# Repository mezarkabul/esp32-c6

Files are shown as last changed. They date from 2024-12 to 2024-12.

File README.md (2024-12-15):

---

# ESP32-C6 Multi-Sensor Board

## Overview
This repository provides the hardware design, block diagrams, and schematics for the ESP32-C6 Multi-Sensor Board. The board integrates Wi-Fi/Bluetooth communication, motor driver control, and IMU sensor, making it suitable for IoT and robotics applications.

esp32-c6-block_diagram

---

## Features & Block Diagram

The ESP32-C6 Multi-Sensor Board includes the following features:

### **Power Management**
- **Power Input:** 5V @ 250mA via connector  
- **Battery Management:**
  - Battery Charger (max 200mA charging current)
  - Voltage Regulator: Converts 4.2V to 3.3V  
  - Battery Level Monitoring via ADC  

### **Microcontroller**
- **ESP32-C6:**
  - Wi-Fi 6 and BLE 5.0 support
  - GPIOs for control and communication  
  - I2C for peripherals  

### **Motor Driver**
- **DRV8830 Motor Driver:**  
  - Controlled via I2C  
  - Outputs: **Motor_P** and **Motor_N**  
  - Supports motor currents up to 400mA  

### **Sensors**
- **IMU (ICM-42605):**  
  - Accelerometer and Gyroscope  
  - Interrupt Pins: **INT1** and **INT2/FSYNC**  

### **User Interface**
- **RGB LED:** Controlled via 3 PWM GPIOs:  
  - **GPIO10:** Red Channel  
  - **GPIO11:** Green Channel  
  - **GPIO12:** Blue Channel  
- **External Button:** GPIO Input for interrupts  

---

## Pinout Table

| **Pin Name** | **ESP32-C6 GPIO**  | **Description** | **Function** |
|---|---|---|---|
| **+V_BAT** | - | Battery Input Voltage | Power Supply |
| **+3V3** | - | 3.3V Regulated Output | Power Supply |
| **+V_POWER_IN** | - | 5V Input | Power Supply |
| **GND** | - | Ground | Power Supply |
| **ESP32_I2C_SCL**  | GPIO8 | I2C Clock | I2C Communication |
| **ESP32_I2C_SDA**  | GPIO9 | I2C Data | I2C Communication |
| **DRV_FAULTN** | GPIO7 | Motor Driver Fault Interrupt | GPIO Input |
| **Motor_P** | - | Motor Driver Output Positive | Motor Control |
| **Motor_N** | - | Motor Driver Output Negative | Motor Control |
| **ICM_INT1/INT** | GPIO5 | IMU Interrupt Pin 1 | IMU Communication |
| **ICM_INT2/FSYNC** | GPIO6 | IMU Interrupt Pin 2 / Sync Pin | IMU Communication |
| **LED_PWM_RED** | GPIO10 | Red Channel of RGB LED | PWM Output |
| **LED_PWM_GREEN**  | GPIO11 | Green Channel of RGB LED | PWM Output |
| **LED_PWM_BLUE** | GPIO12 | Blue Channel of RGB LED | PWM Output |
| **BUTTON** | GPIO4 | External Button Input | GPIO Input |
| **VBAT_MEAS** | GPIO3 | Battery Voltage Meas. 1:2 Ratio  | ADC Input |
| **VIN_MEAS** | GPIO2 | Input Voltage Meas. 1:2 Ratio | ADC Input |
| **ESP32_ENABLE** | GPIO1 | Enable Pin for ESP32 | GPIO Control |

---

## Schematics

The schematics for the project are available:

[esp32_c6_a1_schematic.PDF](https://github.com/user-attachments/files/18142218/esp32_c6_a1_schematic.PDF)

- **Top Page:** High-level connectivity overview
- **SoC Integration:** ESP32-C6 Wifi/BT SoC
- **Power Circuit:** Battery, Charger, and Regulator design
- **Sensors and GPIOs:** ICM-42605, Button, and LED connections

---

### Credits
Designed and documented by **Ali Fatih Demir**.

---

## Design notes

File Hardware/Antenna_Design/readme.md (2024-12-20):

# Antenna Matching Circuit for ESP32-C6

This document provides details for designing an impedance matching circuit to connect an ESP32-C6 microcontroller (input impedance: 35 + 0j Ω) to a 50-ohm antenna. The target operating frequency is 2.425 GHz.

---

## Objective
To design an L-network matching circuit to ensure efficient power transfer between the ESP32-C6 and the antenna by matching their impedances.

---

## Circuit Configuration
Given the antenna impedance (Ω50 Ω) is higher than the ESP32-C6 input impedance (Ω35 Ω), a **low-pass L-network** configuration is used:

- **Series Component**: Inductor (L)
- **Shunt Component**: Capacitor (C)

---

## Component Calculation

resonant_frequency_calculation

---

## Final Component Values
- **Series Inductor (μL)**: **2.2 nH**
- **Shunt Capacitor (μC)**: **4 pF**

---

## Circuit Diagram
```
      Antenna     Series Inductor     ESP32-C6
      -----o---- L (2.2 nH) ----o-----
                 |                  |
                 C (4 pF)      C (4 pF) 
                 |                  |
                GND                GND
```

---

## Notes
1. Component tolerances can affect performance; use precision components for best results.
2. Ensure the PCB layout minimizes parasitic inductance and capacitance.
3. Verify the matching network performance with a vector network analyzer (VNA).

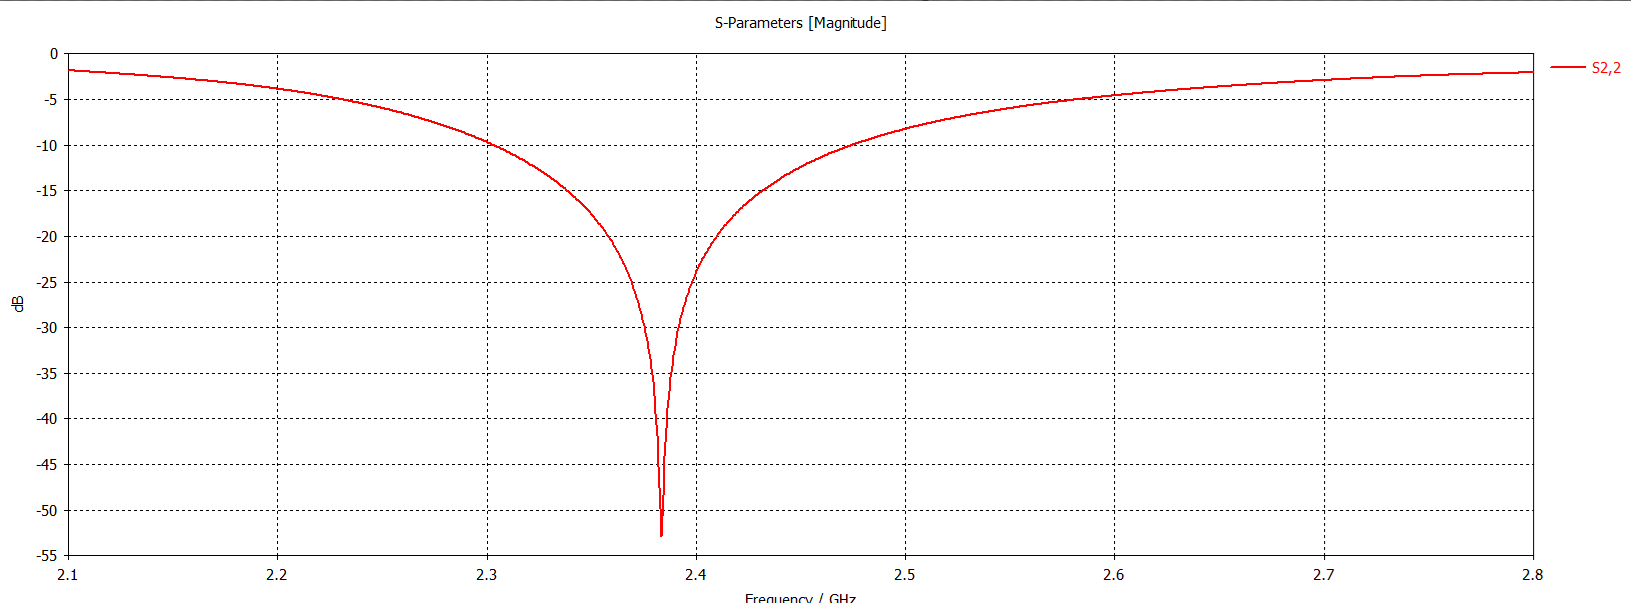
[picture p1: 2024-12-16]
Hardware/Antenna_Design/antenna.png

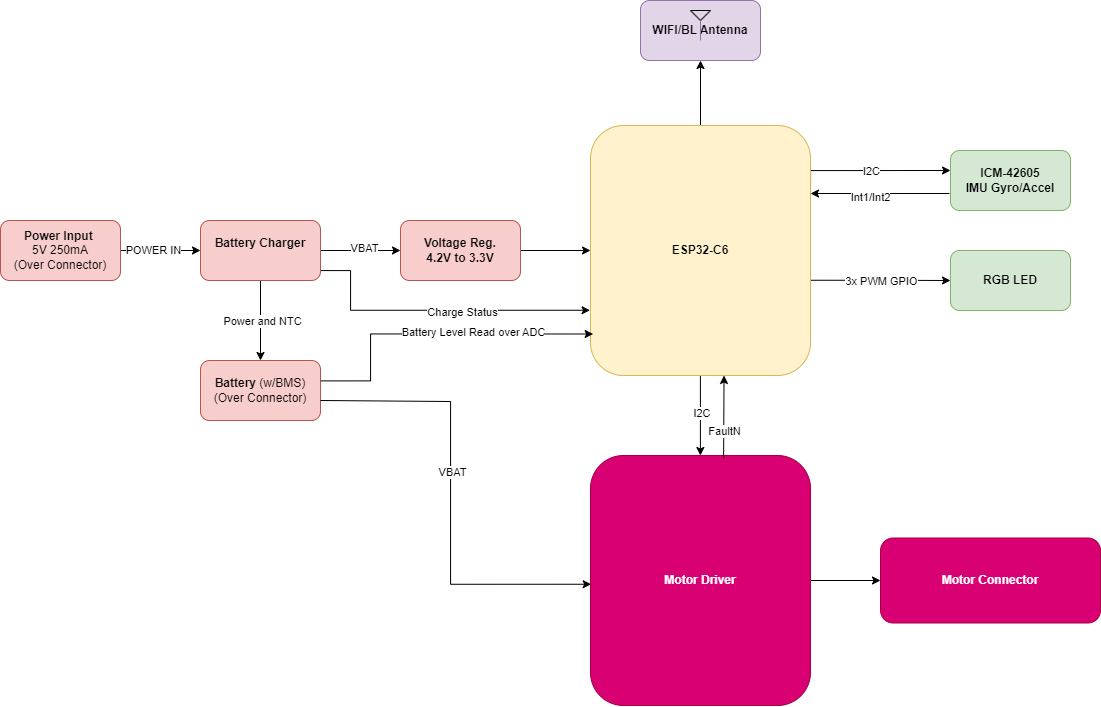
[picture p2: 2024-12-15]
Documentation/esp32-c6-block_diagram.png

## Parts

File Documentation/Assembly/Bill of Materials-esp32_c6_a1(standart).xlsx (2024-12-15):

Designator | Manufacturer | MPN | Value | Description | Footprint | Quantity
C1, C2 | Murata | GRM0335C1H4R0BA01D | 4pF | SMD 0201 Ceramic Chip Capacitor | C_0201 | 2
C3, C9, C14 | Samsung | CL10B105KP8NNNC | 1u | SMD 0603 Ceramic Chip Capacitor | C_0603 | 3
C4, C5 | Murata | GJM1555C1H160FB01J | 16pF | SMD 0402 Ceramic Chip Capacitor | C_0402 | 2
C6, C7, C8, C12, C13, C15, C16, C18, C19, C21, C24, C26, C28, C30, C32 | Samsung | CL05B104KP5NNNC | 100n | SMD 0402 Ceramic Chip Capacitor | C_0402 | 15
C10, C11, C17, C20, C22, C23, C25, C27, C29 | Samsung | CL10A475KP8NNNC | 4.7u | SMD 0603 Ceramic Chip Capacitor | C_0603 | 9
C31 | Samsung | CL05B103KB5NNNC | 10n | SMD 0402 Ceramic Chip Capacitor | C_0402 | 1
D1 | Diodes | BZV55C4V7-TP |  | 16V Clamp 70A (8/20µs) Ipp Tvs Diode Surface Mount SOD-323 | SOD2513X120N | 1
D2 | Everlight Electronics | EAST1616RGBA3 |  | Red, Green, Blue (RGB) - LED Indication - Discrete 1.95V Red, 2.8V Green, 2.8V Blue 0606 (1616 Metric) | LED_EAST1616RGBA3 | 1
F1 | Bourns | MF-FSMF035X-2 |  | Polymeric PTC Resettable Fuse 6V 350mA Ih Surface Mount 0603 _1608 Metric_, Concave | 0603-F1608X100N | 1
J1 | JST | SM03B-GHS-TB |  | CONN HEADER SMD 3POS 1.25MM | jst_sm03b-ghs-tb | 1
J2, J3 | JST | SM02B-GHS-TB |  | CONN HEADER SMD 2POS 1.25MM | JST-SM02B-GHS-TB | 2
L1 | Murata | LQP03TN2N2B02D | 2.2nH | SMD 0201 Inductor | L_0201 | 1
L2 | Murata | LQP03TN24NH02D | 24nH | SMD 0201 Inductor | L_0201 | 1
L3 | Murata | LQG15HN2N0C02D | 2nH | SMD 0402 Inductor | L_0402 | 1
M1 | TBD | TBD |  | RF Cover | rf-cover | 1
R1, R2, R4, R5, R9, R10, R15, R25, R26 | Yageo | RC0402FR-0710KL | 10k, 100k | SMD 0402 Rectangular Thick Film Chip Resistor | R_0402 | 9
R3, R7, R12, R20, R21, R22 | Yageo | RC0402FR-07499RL | 499R | SMD 0402 Rectangular Thick Film Chip Resistor | R_0402 | 6
R6, R8, R11, R13 | Yageo | RC0402FR-07475KL | 475k | SMD 0402 Rectangular Thick Film Chip Resistor | R_0402 | 4
R14, R17, R23, R24 | Yageo | RC0402FR-0733RL | 33R | SMD 0402 Rectangular Thick Film Chip Resistor | R_0402 | 4
R16 | Yageo | RC0402FR-072K7L | 2.7k | SMD 0402 Rectangular Thick Film Chip Resistor | R_0402 | 1
R18, R19 | Yageo | RC0603FR-071RL | 1R | SMD 0603 Rectangular Thick Film Chip Resistor | R_0603 | 2
SW1 | E-Switch | TL3365AF180QG |  | Tactile Switch SPST-NO Top Actuated Surface Mount | SW_TL3365AF180QG | 1
U1 | Espressif Systems | ESP32-C6FH4 |  | 802.15.4, Bluetooth, WiFi 802.11ax, Bluetooth v5.0, ZigbeeÂ® Transceiver Module 2.4GHz Antenna Not Included Surface Mount | QFN50P500X500X90-33N | 1
U2 | BQ21040DBVT | BQ21040DBVT |  | 1-cell, 0.8-A Li-ion and Li-polymerymer battery charger 6-SOT-23 0 to 125 | SOT95P280X110-6N | 1
U3 | Texas Instruments | DRV8830DGQR |  | 6.8-V, 1-A H-bridge motor driver with speed regulation and i2c control 10-HVSSOP -40 to 85 | IC_XTR111AIDGQR | 1
U4 | Texas Instruments | TPS7A2033PDBVR |  | Linear Voltage Regulator IC Positive Fixed 1 Output 300mA SOT-23-5 | SOT95P280X110-5N | 1
U5 | TDK Invensense | ICM-42605 |  |  | XDCR_ICM-42605 | 1
Y1 | ECS Inc. | ECS-400-10-37B2-CKY-TR |  | 40 MHz Â±10ppm Crystal 10pF 40 Ohms 4-SMD, No Lead | XTAL_ECS-400-10-37B2-CKY-TR | 1

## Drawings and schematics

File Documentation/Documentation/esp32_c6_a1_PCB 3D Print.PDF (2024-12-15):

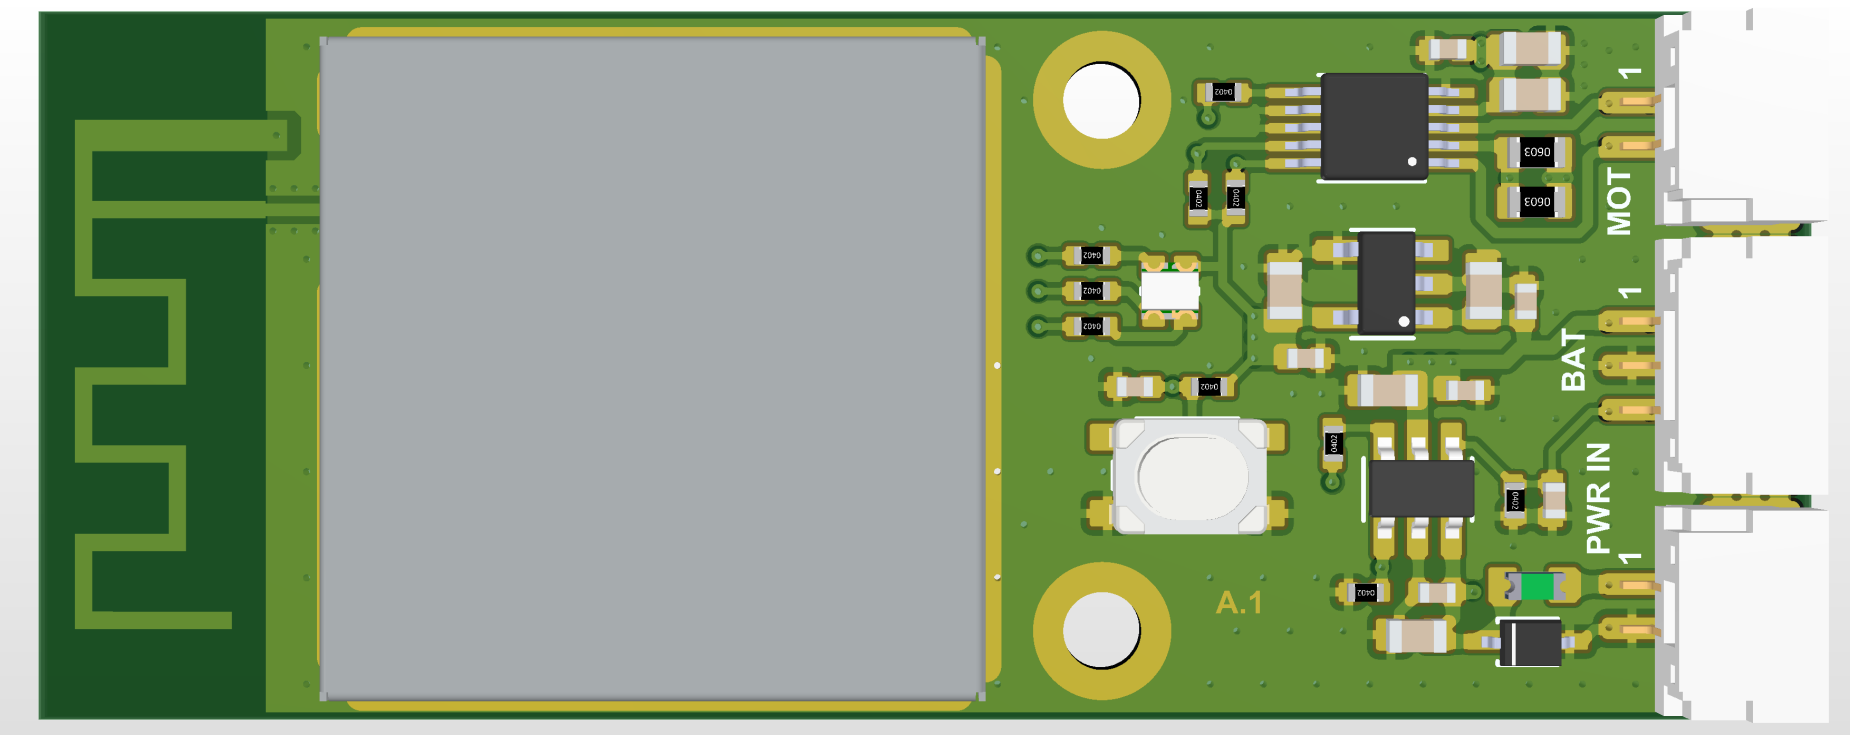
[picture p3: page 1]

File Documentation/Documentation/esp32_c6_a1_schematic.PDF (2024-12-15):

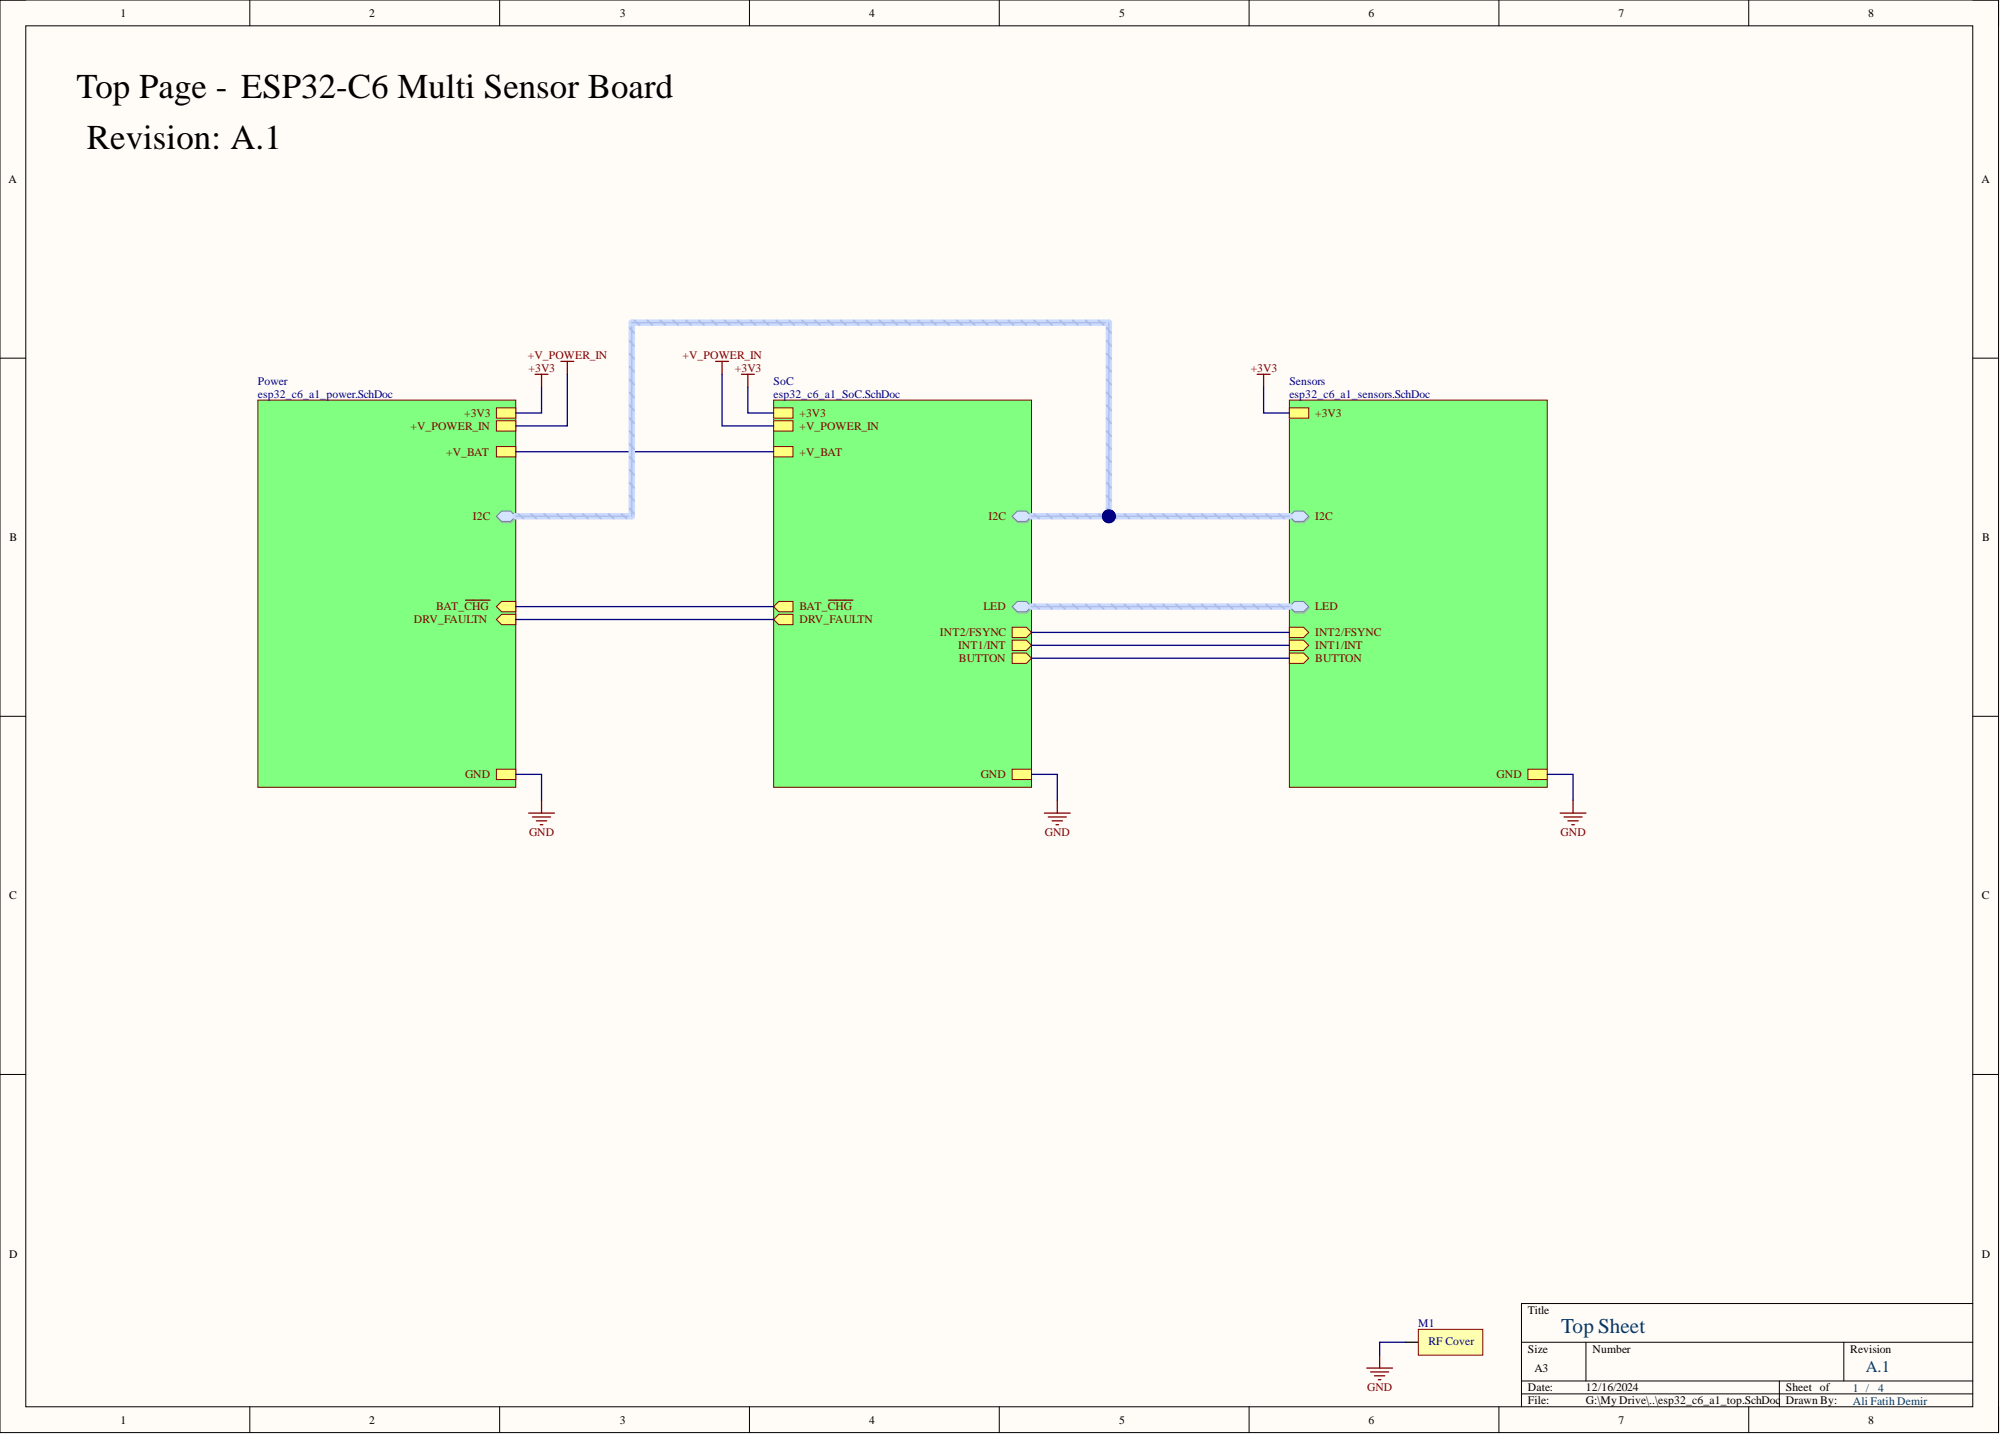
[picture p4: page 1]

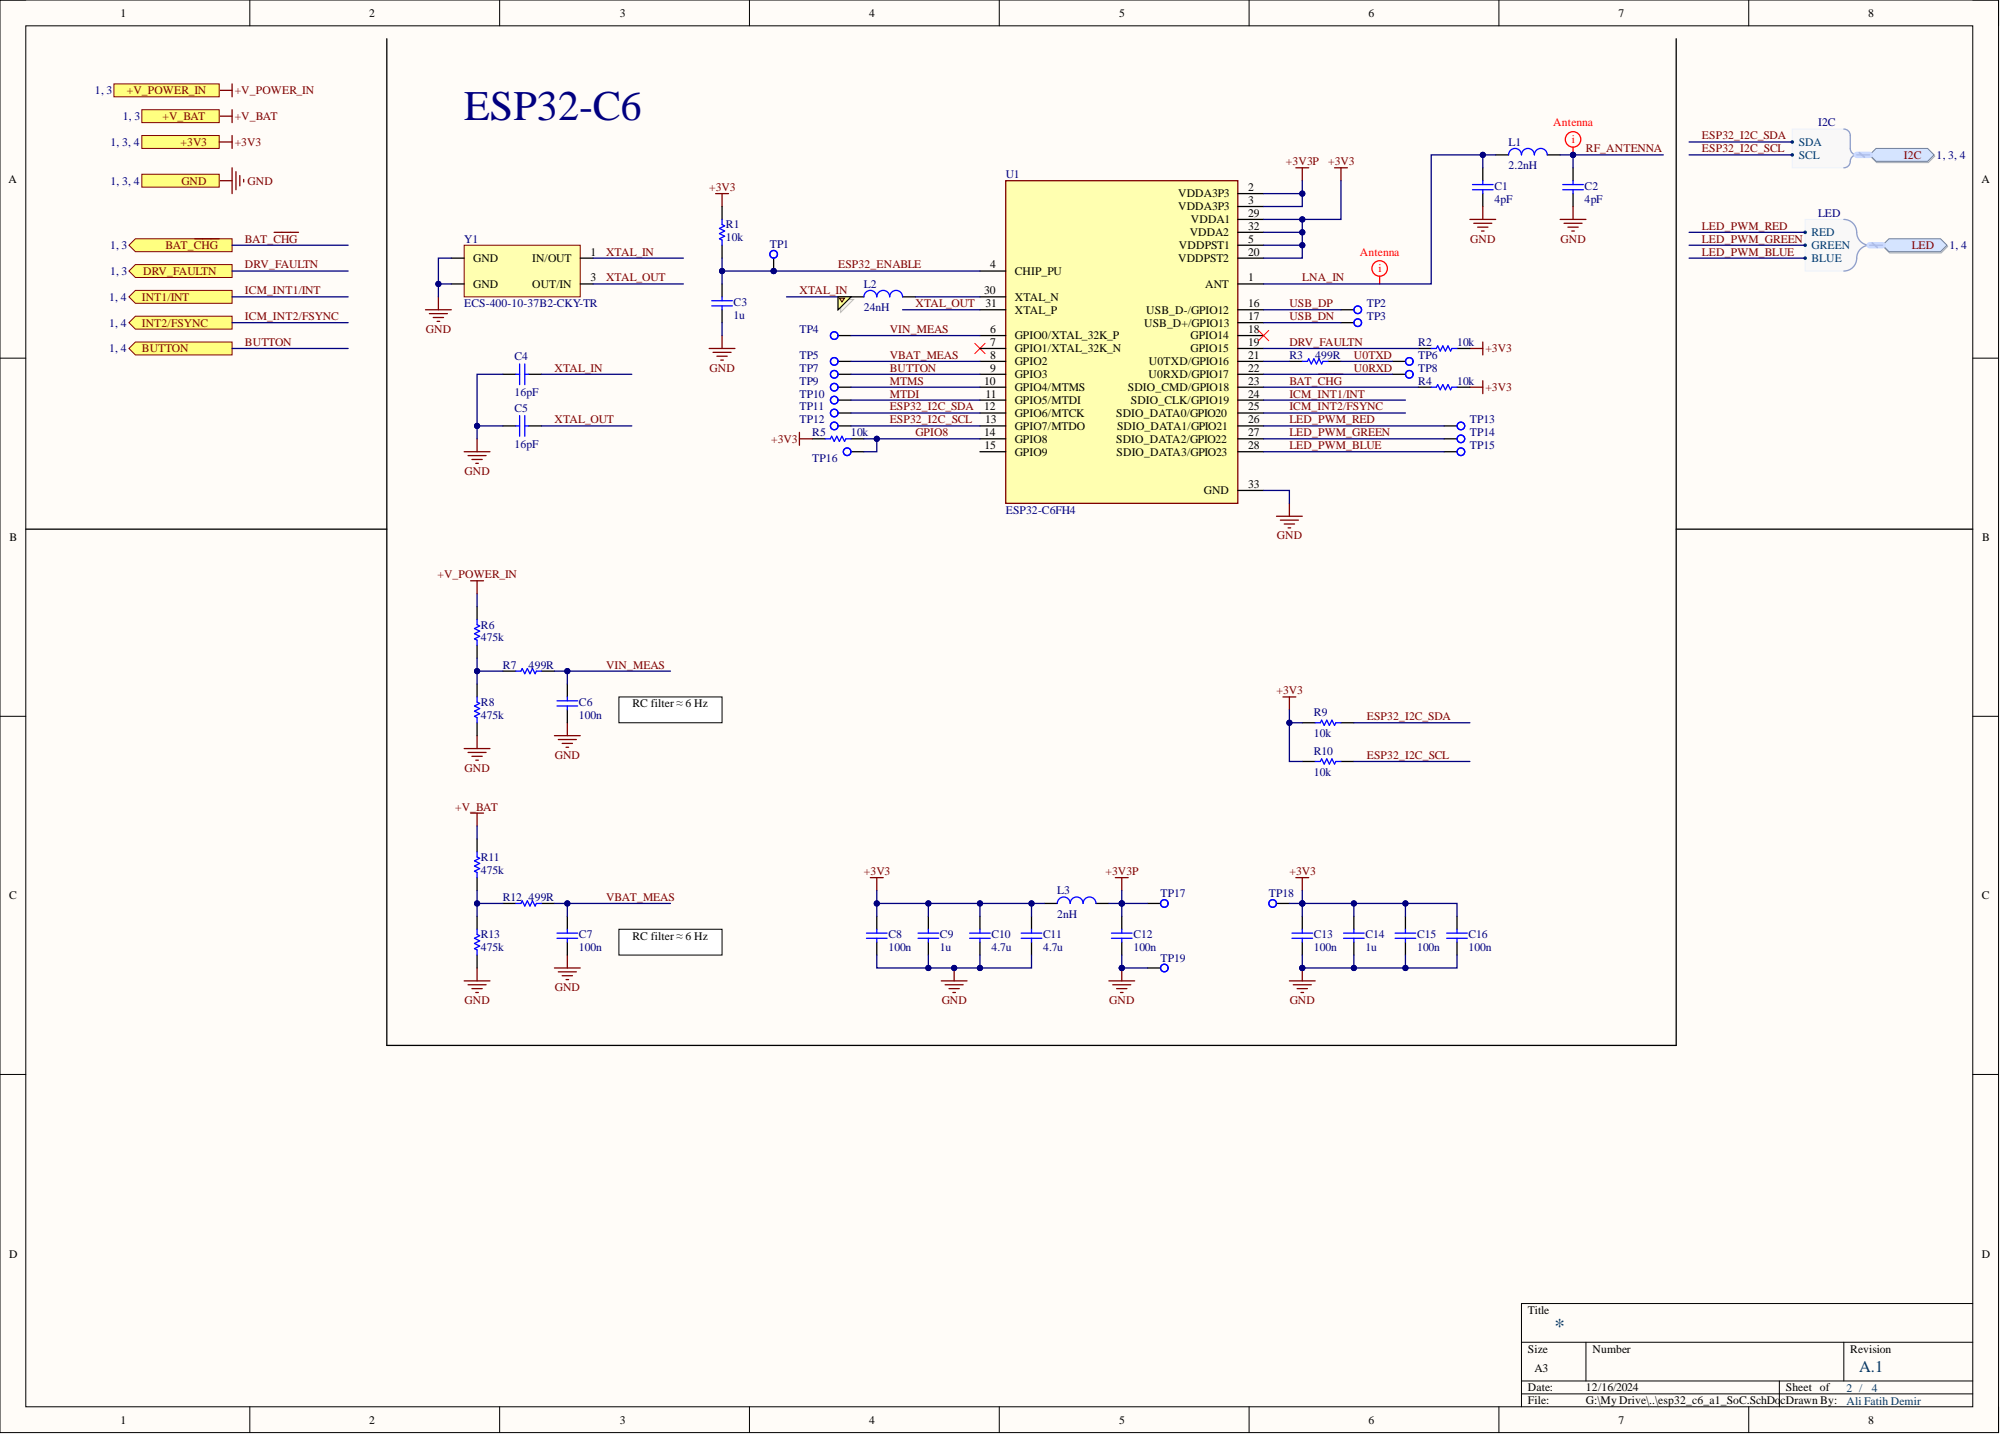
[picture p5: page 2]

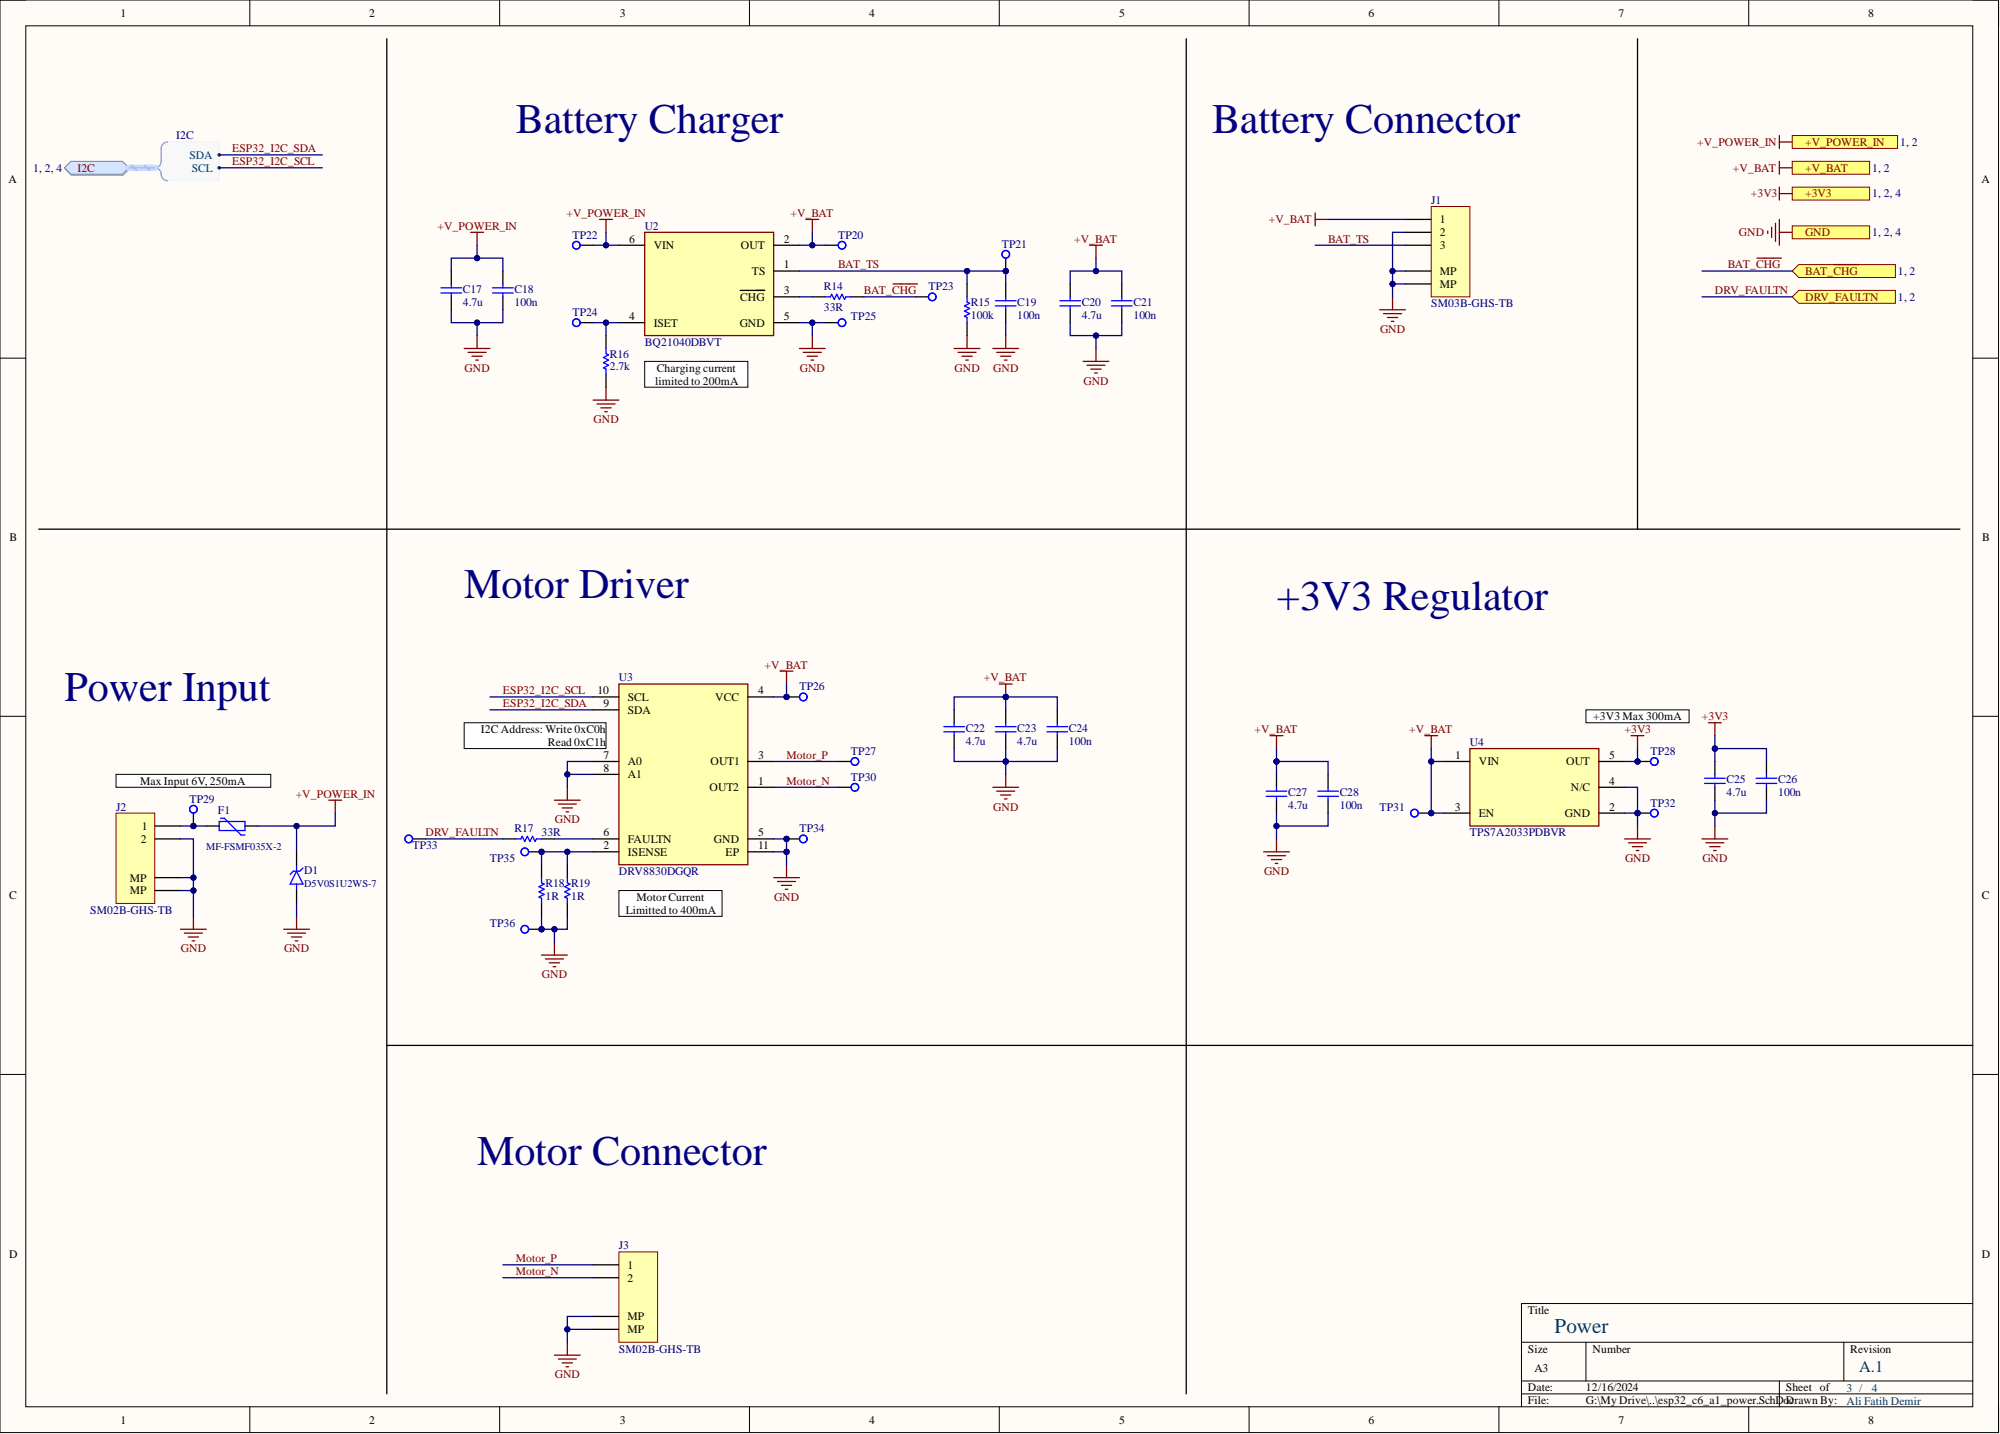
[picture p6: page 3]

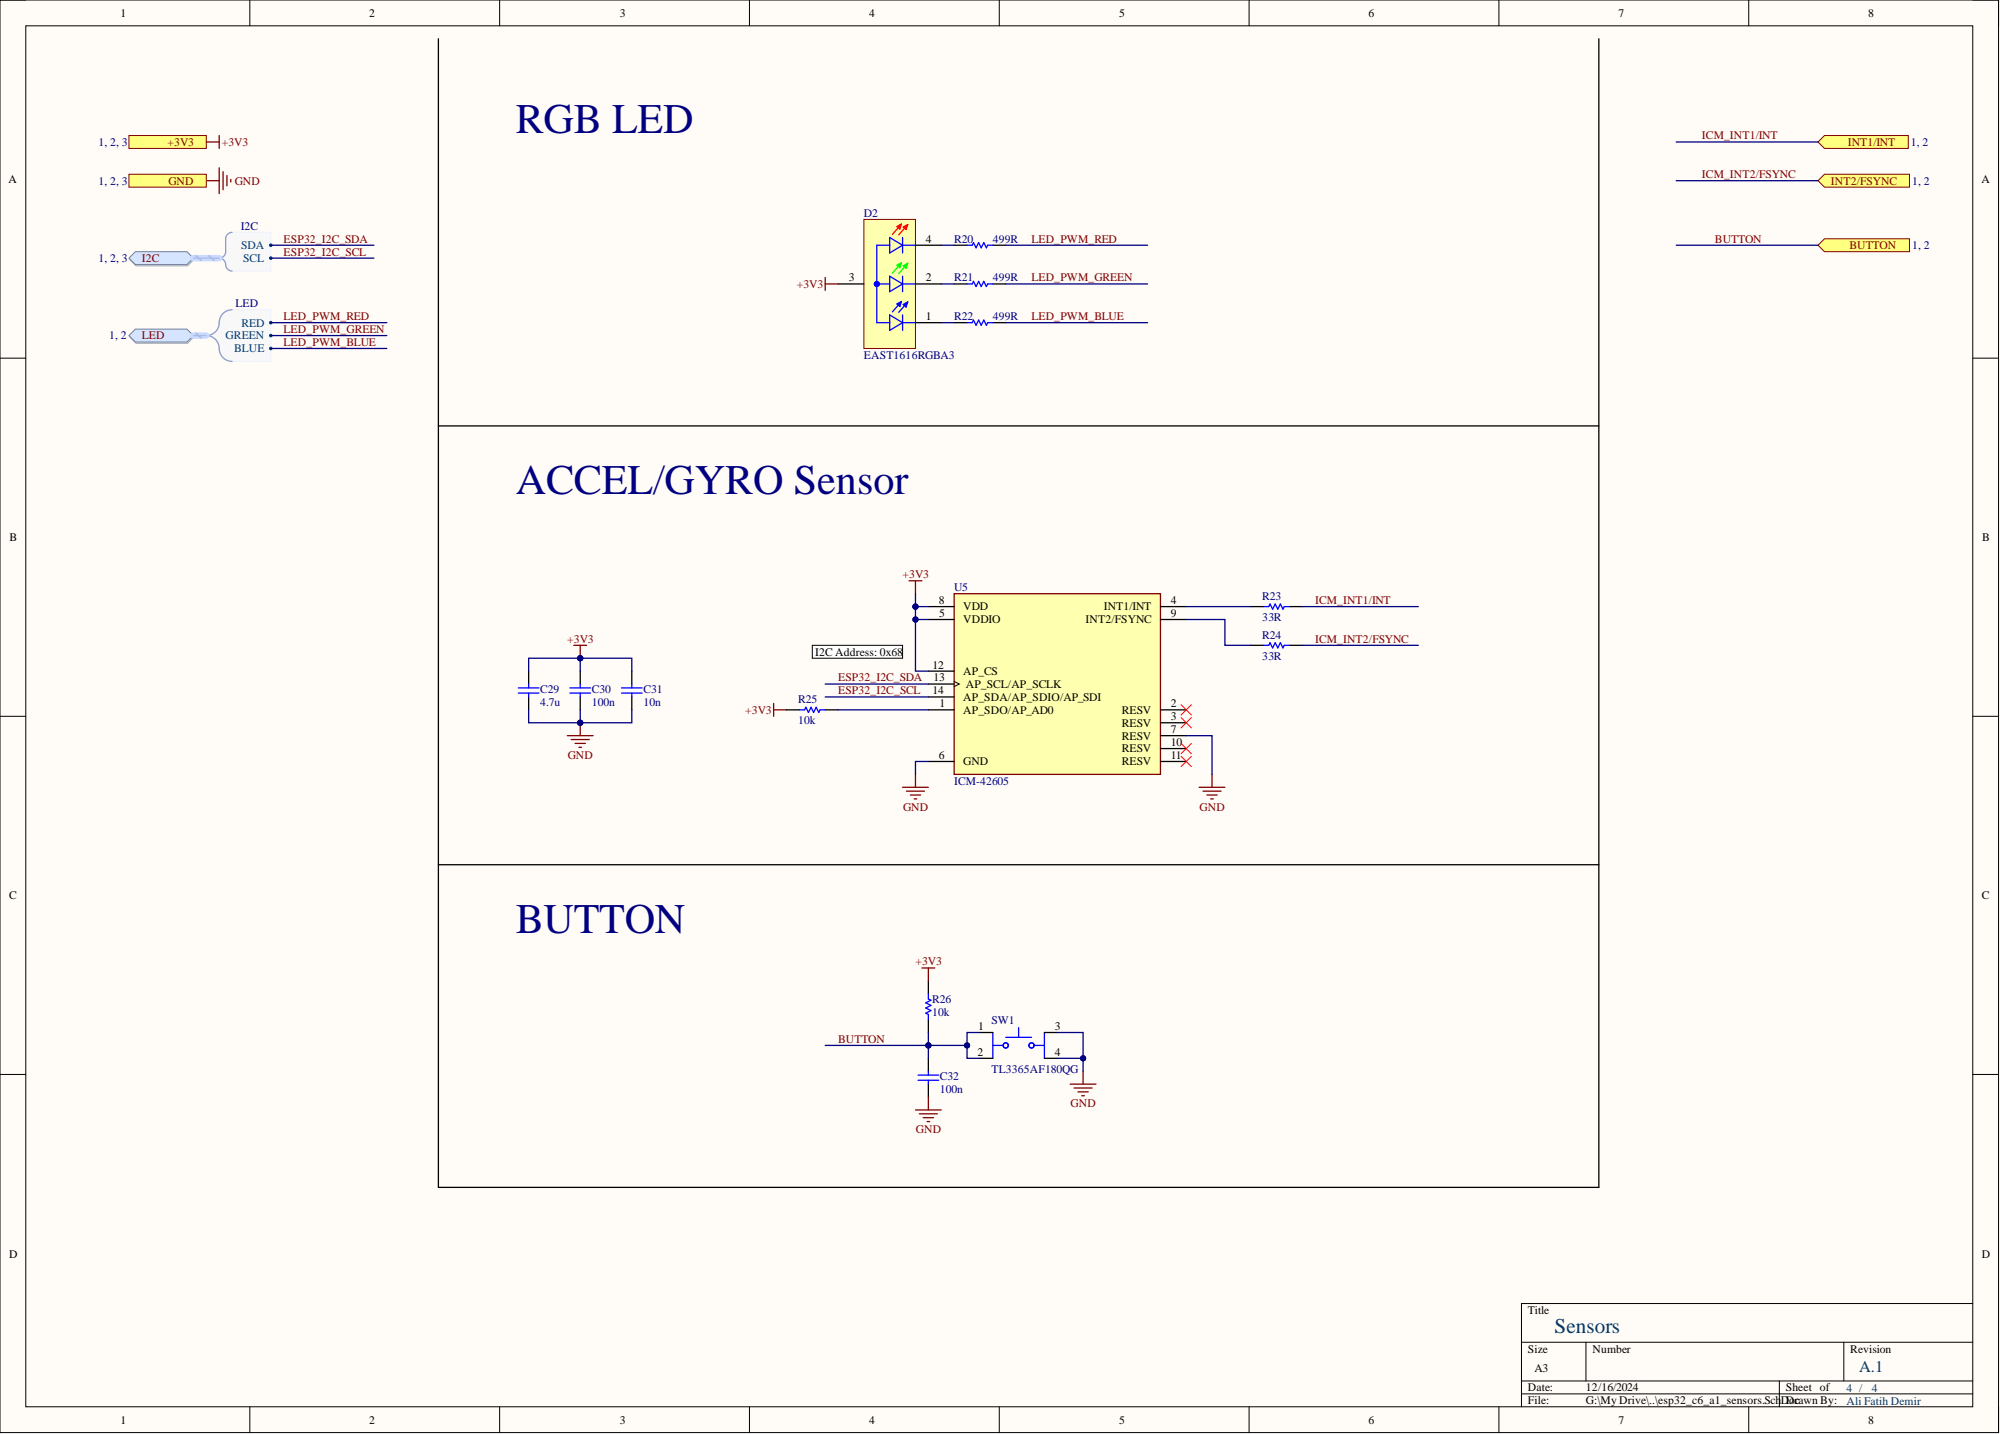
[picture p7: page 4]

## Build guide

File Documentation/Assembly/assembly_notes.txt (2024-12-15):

Assembly Notes:

1. All the parts and materials shall be ROHS3 Compliant, REACH Unaffected, and halogen free.
2. The assembly should comply with IPC-A-610 Class 2 standards.

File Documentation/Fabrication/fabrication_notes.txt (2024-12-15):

Fabrication Notes:

1.  PCB specifications:
    Board Size: 20mm x 50mm
    Board Thickness: 1.0mm +-10%
    Solder Stop Color:  Black
    Silkscreen:  White, Both sides
    Number of Layers: 4
    Clearance / Minimum width / Minimum Annular Ring: 0.135mm/0.1mm/0.1mm
    Minimum Hole Size: 0.3mm
    Surface: Enig
    Impedance Control: Yes
    Micro Via: -
    Burried Via: -

2.  This PCB is designed to meet performance class 2 specifications outlined in IPC-2221. The bare PCB must undergo testing for test level B as per IPC-9252 standard.
3.  Please add UL recognized marking relevant to UL94V-0 and UL 796 on the PCB or panel.
4.  The PCB should comply with IPC-A-600 Class 2 standards.
5.  All the parts and materials shall be ROHS3 Compliant, REACH Unaffected, and halogen free.
6.  All the distributors and manufacturers are obliged to care about conflict free minerals in their supply chain.

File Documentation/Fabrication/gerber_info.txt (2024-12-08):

GTO  - Top Overlay (silkscreen)
GBO  - Bottom Overlay (silkscreen)
GTS  - Top Solder Mask
GBS  - Bottom Solder Mask
GTP  - Top Paste Mask
GBP  - Bottom Paste Mask

GTL  - Top Layer
GBL  - Bottom Layer
Gx   - Signal Layer x
GPx  - Plane x

GM1  - Board Border
GM2  - Panel Border
GM3  - V-Cut
GM4  - Cut-Out
GM5  - Fabrication Notes
GM6  - Assembly Notes
GM7  - Designators Top
GM8  - Designators Bottom
GM9  - Notes Top
GM10 - Notes Bottom
GM11 - Body Top
GM12 - Body Bottom
GM13 - Outline Top
GM14 - Outline Bottom
GM15 - Courtyard Top
GM16 - Courtyard Bottom
GM17 - Object Top
GM18 - Object Bottom
GM31 - Dimensions
GM32 - Sheet

GPT - Gerber Top Pad Master
GPB - Gerber Bottom Pad Master
GKO - Gerber Keepout

GDx - Gerber Drill Drawing x
GGx - Gerber Drill Guide x

REP - Report file
TXT - ASCII NC Drill
DRL - EIA NC Drill
DRR - NC Drill Report
APR - Aperature File

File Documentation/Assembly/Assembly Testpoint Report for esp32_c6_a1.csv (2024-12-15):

Net | Name | X Coord | Y Coord | Side | Hole Size | Type
VIN_MEAS | TP4-1 | 20.2mm | 3.4mm | Bottom | 0mm | Surface mount
NetF1_2 | TP29-1 | 44.9mm | 4.6mm | Bottom | 0mm | Surface mount
DRV_FAULTN | TP33-1 | 34mm | 17mm | Bottom | 0mm | Surface mount
MTDI | TP10-1 | 14.9mm | 4.6mm | Bottom | 0mm | Surface mount
MTMS | TP9-1 | 13.3mm | 3.2mm | Bottom | 0mm | Surface mount
+3V3P | TP17-1 | 10.2mm | 10.9mm | Bottom | 0mm | Surface mount
VBAT_MEAS | TP5-1 | 12.4mm | 5mm | Bottom | 0mm | Surface mount
+3V3 | TP28-1 | 35.1mm | 10.8mm | Bottom | 0mm | Surface mount
GND | TP32-1 | 36.6mm | 13.3mm | Bottom | 0mm | Surface mount
USB_DP | TP2-1 | 17.6mm | 5.1mm | Bottom | 0mm | Surface mount
LED_PWM_BLUE | TP15-1 | 28.1mm | 14.1mm | Bottom | 0mm | Surface mount
ESP32_ENABLE | TP1-1 | 11.1mm | 2.5mm | Bottom | 0mm | Surface mount
ESP32_I2C_SDA | TP11-1 | 16mm | 2.9mm | Bottom | 0mm | Surface mount
BUTTON | TP7-1 | 32.1mm | 10.3mm | Bottom | 0mm | Surface mount
USB_DN | TP3-1 | 19.8mm | 7.4mm | Bottom | 0mm | Surface mount
U0TXD | TP6-1 | 21.9mm | 9.7mm | Bottom | 0mm | Surface mount
LED_PWM_RED | TP13-1 | 28.9mm | 10mm | Bottom | 0mm | Surface mount
ESP32_I2C_SCL | TP12-1 | 18.1mm | 3.1mm | Bottom | 0mm | Surface mount
LED_PWM_GREEN | TP14-1 | 27.4mm | 12.2mm | Bottom | 0mm | Surface mount
U0RXD | TP8-1 | 19.8mm | 9.8mm | Bottom | 0mm | Surface mount
GPIO8 | TP16-1 | 16.2mm | 6.7mm | Bottom | 0mm | Surface mount
GND | TP19-1 | 10.4mm | 8.9mm | Bottom | 0mm | Surface mount
+3V3 | TP18-1 | 21.1mm | 13.5mm | Bottom | 0mm | Surface mount
+V_POWER_IN | TP22-1 | 40.5mm | 4.4mm | Bottom | 0mm | Surface mount
+V_BAT | TP20-1 | 44.9mm | 11.8mm | Bottom | 0mm | Surface mount
NetR16_1 | TP24-1 | 37mm | 4.3mm | Bottom | 0mm | Surface mount
+V_BAT | TP31-1 | 39.9mm | 11mm | Bottom | 0mm | Surface mount
BAT_TS | TP21-1 | 44.9mm | 8mm | Bottom | 0mm | Surface mount
GND | TP34-1 | 35.3mm | 18.7mm | Bottom | 0mm | Surface mount
GND | TP25-1 | 39.1mm | 6.4mm | Bottom | 0mm | Surface mount
BAT_C\H\G\ | TP23-1 | 36mm | 7.6mm | Bottom | 0mm | Surface mount
Motor_N | TP30-1 | 44.9mm | 15.5mm | Bottom | 0mm | Surface mount
Motor_P | TP27-1 | 44.9mm | 18mm | Bottom | 0mm | Surface mount
GND | TP36-1 | 42.6mm | 13.8mm | Bottom | 0mm | Surface mount
NetR18_2 | TP35-1 | 41.5mm | 16.1mm | Bottom | 0mm | Surface mount
+V_BAT | TP26-1 | 39.9mm | 17.8mm | Bottom | 0mm | Surface mount

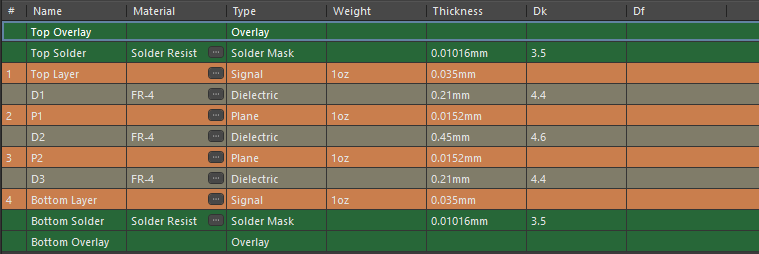
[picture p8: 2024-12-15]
Documentation/Fabrication/esp32_c6_a1_stackup.png

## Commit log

2024-12-08 initial hardware
    [esp32_c6_a1.PcbDoc, esp32_c6_a1.PrjPcb, esp32_c6_a1_mcu.SchDoc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]
2024-12-10 Completed Schematic Design Updated Schematic Structure
    [esp32_c6_a1.PcbDoc, esp32_c6_a1.PrjPcb, esp32_c6_a1_SoC.SchDoc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]
2024-12-11 Done Placement Update PCB Minor Fix Schematic
    [esp32_c6_a1.PcbDoc, esp32_c6_a1_SoC.SchDoc, esp32_c6_a1_power.SchDoc]
2024-12-11 Ongoing PCB Routing Fix minor Schematic problems
    [esp32_c6_a1.PcbDoc, esp32_c6_a1_SoC.SchDoc, esp32_c6_a1_sensors.SchDoc]
2024-12-12 Complete layout Fix minor schematic problems
    [esp32_c6_a1.PcbDoc, esp32_c6_a1.PrjPcb, esp32_c6_a1_SoC.SchDoc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]
2024-12-12 Saving Properly, Minor Layout improments
    [esp32_c6_a1.PcbDoc]
2024-12-12 Fix Color
    [esp32_c6_a1.PcbDoc]
2024-12-15 Added outputjob file Fixed PI circuit value
    [esp32_c6_a1.PrjPcb, esp32_c6_a1_SoC.SchDoc, esp32_c6_a1_power.SchDoc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]
2024-12-15 Upload Documentation
    [Assembly Testpoint Report for esp32_c6_a1.csv, Bill of Materials-esp32_c6_a1(standart).xlsx]
2024-12-15 add RF Shield
    [esp32_c6_a1.PrjPcb, esp32_c6_a1_top.SchDoc]
2024-12-15 Update Docs
    [Assembly Testpoint Report for esp32_c6_a1.csv, Bill of Materials-esp32_c6_a1(standart).xlsx]
2024-12-16 Update Antenna
2024-12-20 Add antenna calculation
2024-12-20 Update Antenna calculation
